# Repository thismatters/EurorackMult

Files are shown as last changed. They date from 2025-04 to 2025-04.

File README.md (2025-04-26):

# Signal Multiplier

The signal mulitplier, as the name implies, multiplies signals. This module is an active mult, meaning that the input signal is buffered and the output duplicate signals are also individually buffered to ensure the signal is faithfully duplicated.

This is an original design featuring a three-layer stackup with a front face, a layer for all the jacks, and a power/processing layer where all the SMD components are layed out.

As with other modules in this line, this mult features:
* Polarity protection so that a backward power header doesn't fry anything (twin series schotty diodes: BAT54SL),
* Full surface mount design.

The KiCAD project here uses the library/footprints [found in my companion repo](https://github.com/thismatters/EurorackKiCAD).

## Width

12hp on an [Intellijel 1U rack](https://intellijel.com/support/1u-technical-specifications/).

## Inputs

There are two signal jacks, the lower one normals to the upper.

## Outputs

There are six output jacks with the top set being fed by the top input, and the bottom set being fed by the bottom input. If there is no jack plugged into the bottom input socket then the bottom outputs will output the upper input's signal.

## Adjustment

No adjustment required.

## Vendors

There are part numbers in the [BOM](mult.csv) for many of the parts (not for basic passives though) at the following vendors:

* [Mouser](https://www.mouser.com): Needs no introduction. Get your ICs from here (or [digikey](https://www.digikey.com)).
* [Tayda Electronics](https://www.taydaelectronics.com/): Good supplier for passive components; audio jacks, and potentiometers. Their audio jacks are slightly smaller than the thonkiconn from thonk.
* [Love My Switches](https://lovemyswitches.com/): Has [really good knobs](https://lovemyswitches.com/anodized-aluminum-knob-the-lo-fi-1-4-smooth-shaft-12-5mm-od/) to go on those potentiometers!
* [OSHPark](https://oshpark.com/): Fast and (relatively) cheap PCB manufacturer. The [V0 circuit](https://oshpark.com/shared_projects/0YTEwnCD) has some issues (outlined below), use at your own risk.

## Changelog

### V1
- Removed extra Op Amp and replaced a TL074 with TL072
- Removed several resistors
- Updated design language
- Added standoffs between component board and jack board (increased module width to accomodate)
- Fixed some other bugs

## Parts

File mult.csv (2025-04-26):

# | Reference | Qty | Value | Footprint | DNP | Vendor | PartNum
1 | C1, C2 | 2 | 22u 50V | Capacitor_THT:CP_Radial_D5.0mm_P2.50mm
2 | C3, C4 | 2 | 100n | Capacitor_SMD:C_0805_2012Metric
3 | D1, D2 | 2 | BAT54S | Package_TO_SOT_SMD:SOT-23 |  | Mouser | 863-BAT54SLT1G
4 | J1 | 1 | Conn_02x05_Odd_Even | Eurorack:PinHeader_2x05_P2.54mm_Vertical |  | Tayda | A-2939
5 | J2, J3, J4, J5, J6, J7, J8, J9 | 8 | AudioJack2_SwitchT | Eurorack:AudioJack2_Tayda_A-2566 |  | Tayda | A-2566
6 | J10, J11, J12 | 3 | Conn_01x03_Pin | Connector_PinHeader_2.54mm:PinHeader_1x03_P2.54mm_Vertical
7 | J13, J14, J15 | 3 | Conn_01x03_Socket | Connector_PinSocket_2.54mm:PinSocket_1x03_P2.54mm_Vertical
8 | M1, M2 | 2 | Standoff | Eurorack:Standoff_M2.5x0.45-11mm |  | Digikey | 732-10549-ND
9 | M3, M4, M5, M6 | 4 | Screw | Eurorack:Screw_M2.5x0.45-6mm |  | Digikey | 36-29301-ND
10 | R1, R2 | 2 | 10 | Resistor_SMD:R_0805_2012Metric
11 | R3, R4, R5, R6, R7, R8 | 6 | 1K | Resistor_SMD:R_0805_2012Metric
12 | U1 | 1 | TL074 | Package_SO:SOIC-14_3.9x8.7mm_P1.27mm |  | Mouser | 595-TL074CDR
13 | U2 | 1 | TL072 | Package_SO:SOIC-8_3.9x4.9mm_P1.27mm |  | Mouser | 595-TL072CDR

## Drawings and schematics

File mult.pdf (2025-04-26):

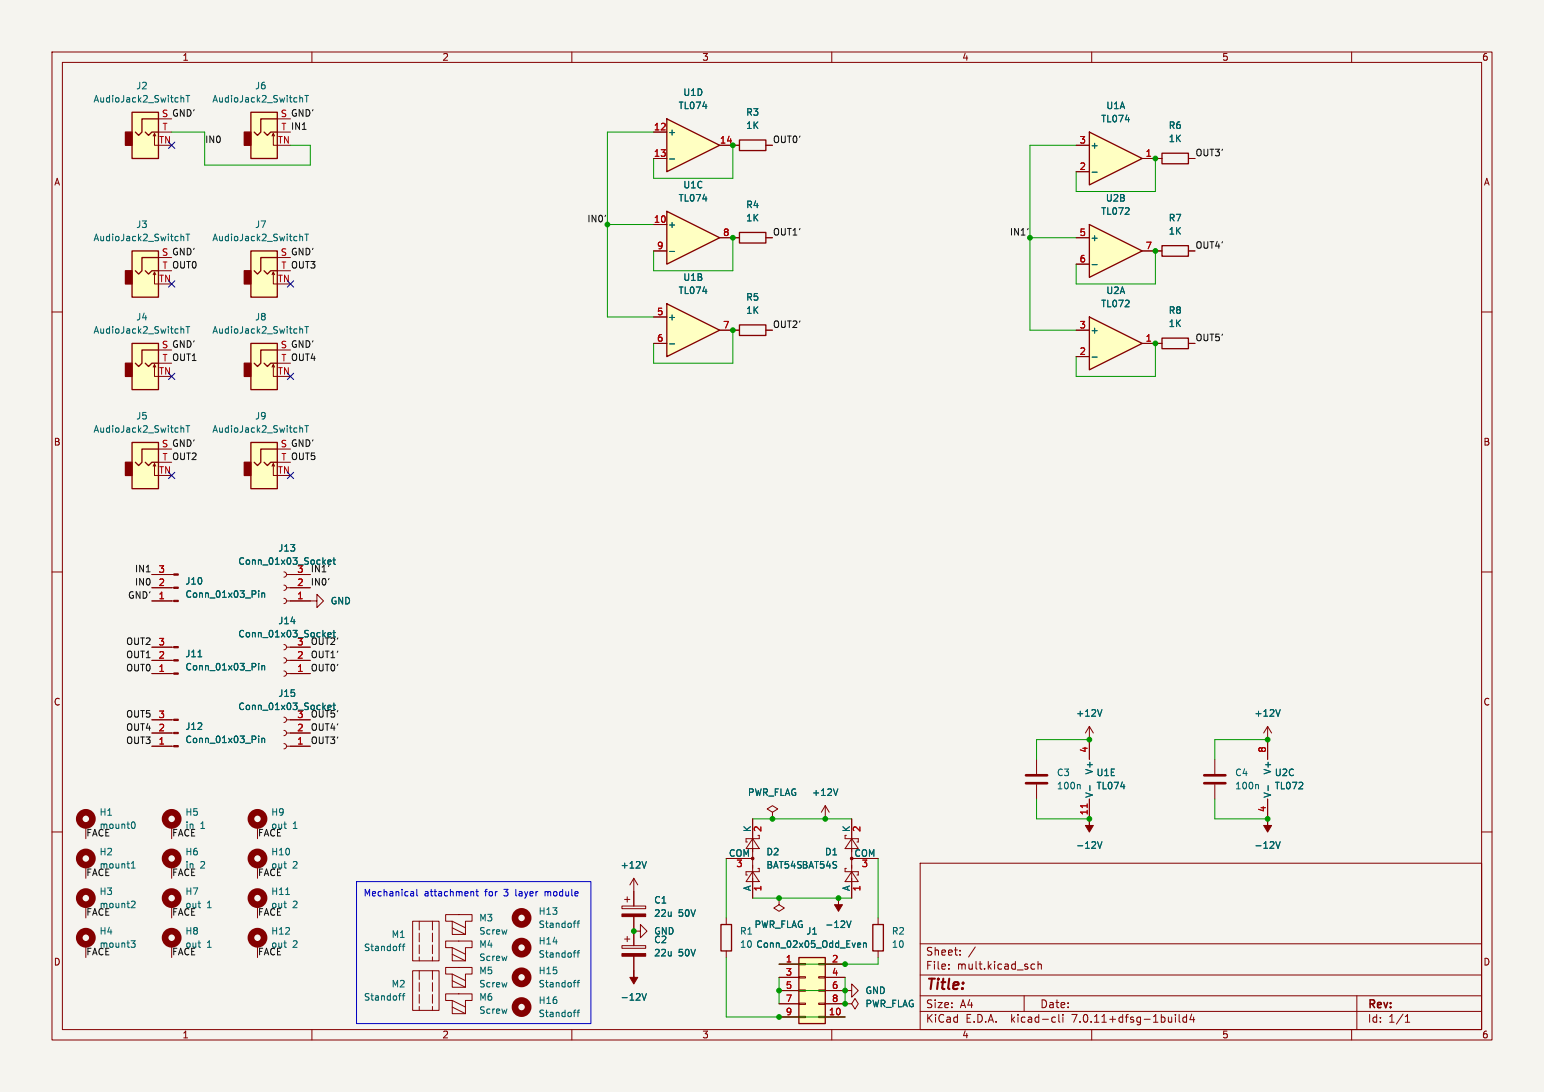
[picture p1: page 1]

Id: 1/1 Title: File: mult.kicad_sch Sheet: / R1

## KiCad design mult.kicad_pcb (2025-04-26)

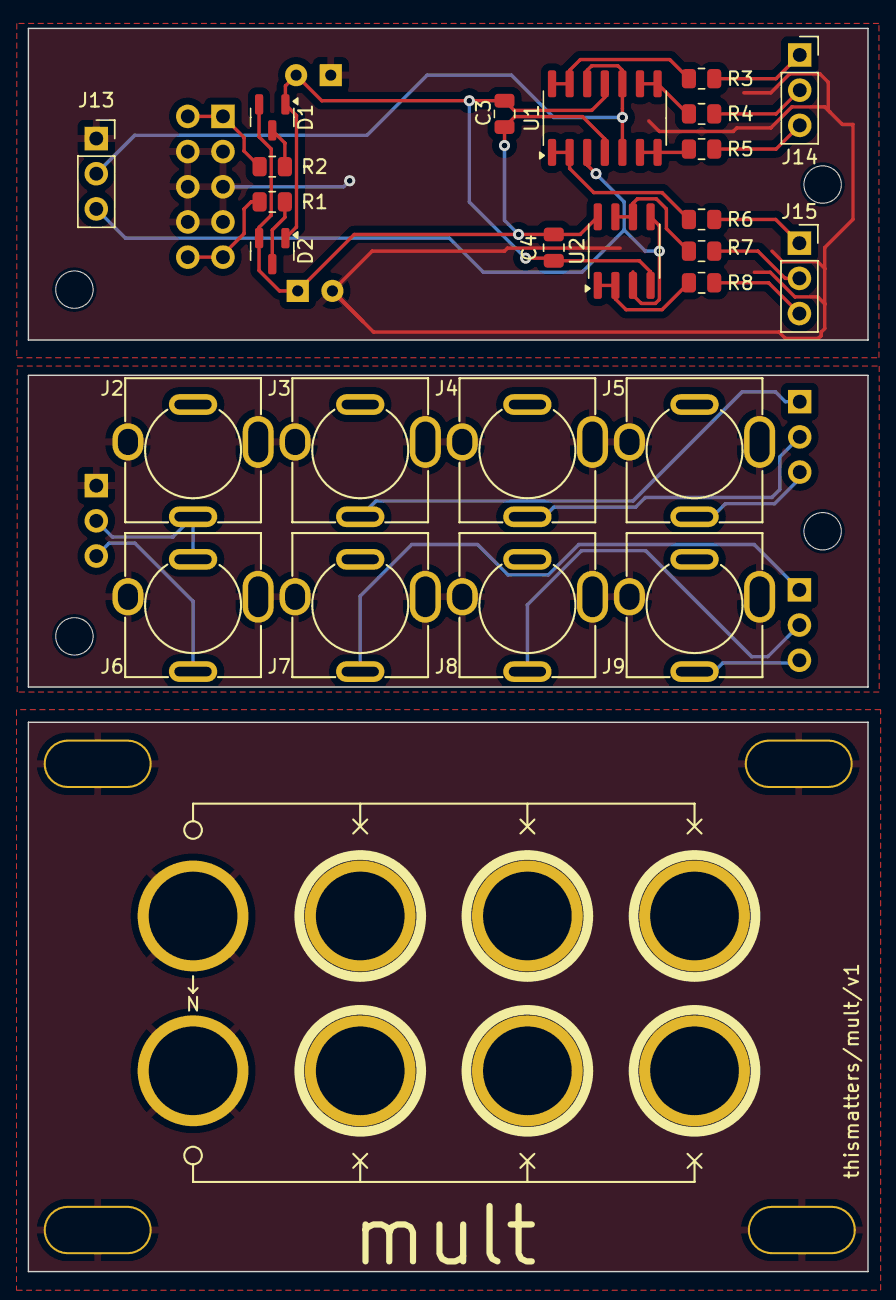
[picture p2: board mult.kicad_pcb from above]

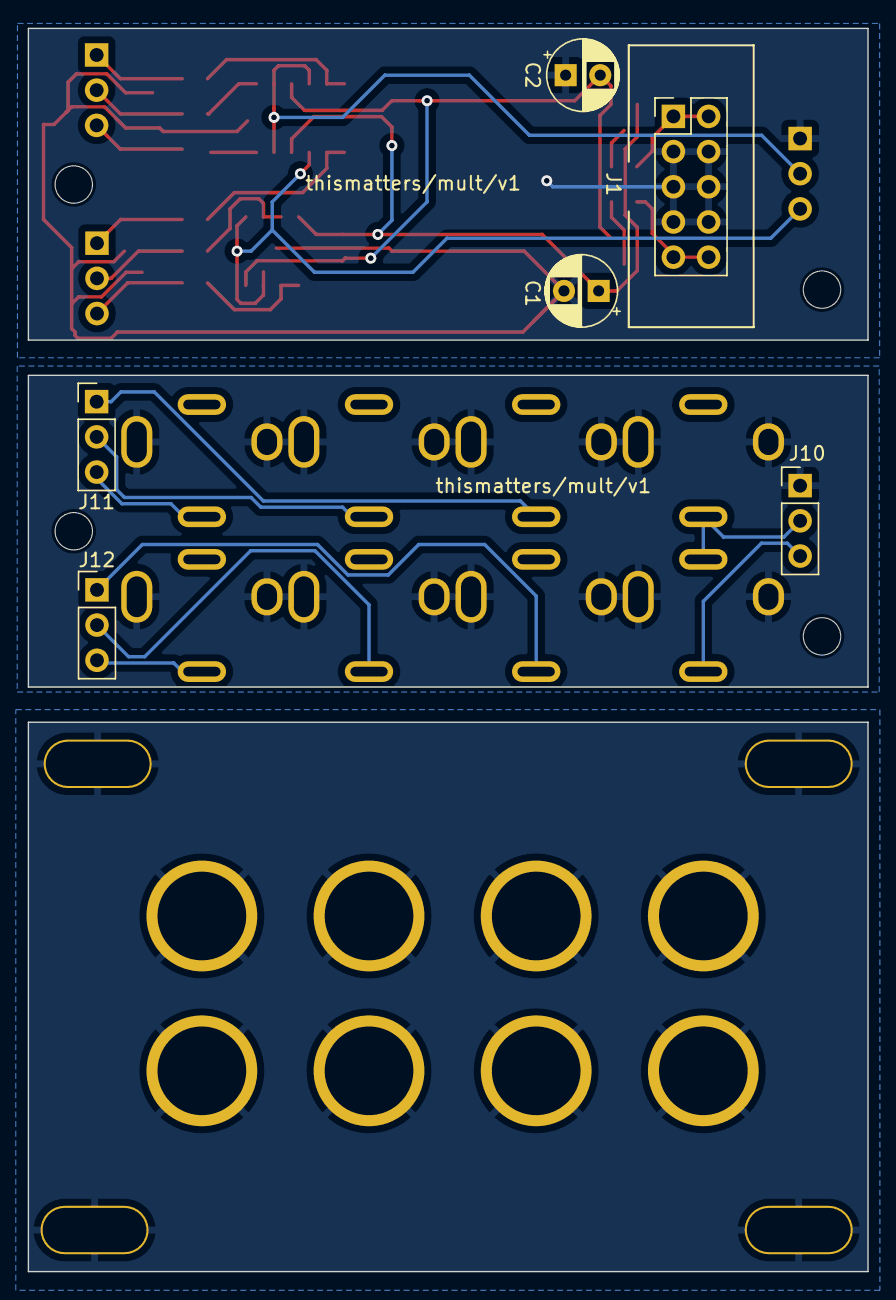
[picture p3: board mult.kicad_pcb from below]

Board: 2 copper layers, 60.6 x 89.7 mm, 47 parts (7 on the bottom side), 31 nets.

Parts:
C1, C2: 22u 50V; CP_Radial_D5.0mm_P2.50mm
C3, C4: 100n; C_0805_2012Metric
D1, D2: BAT54S; SOT-23
H1: mount0; Mech-MountingHole
H2: mount1; Mech-MountingHole
H3: mount2; Mech-MountingHole
H4: mount3; Mech-MountingHole
H5: in 1; Mech-AudioJack-Hole
H6: in 2; Mech-AudioJack-Hole
H7, H8, H9: out 1; Mech-AudioJack-Hole-Output
H10, H11, H12: out 2; Mech-AudioJack-Hole-Output
H13, H14, H15, H16: Standoff; MountingHole_2.7mm_M2.5
J1: Conn_02x05_Odd_Even; PinHeader_2x05_P2.54mm_Vertical
J2, J3, J4, J5, J6, J7, J8, J9: AudioJack2_SwitchT; AudioJack2_Tayda_A-2566
J10, J11, J12: Conn_01x03_Pin; PinHeader_1x03_P2.54mm_Vertical
J13, J14, J15: Conn_01x03_Socket; PinSocket_1x03_P2.54mm_Vertical
R1, R2: 10; R_0805_2012Metric
R3, R4, R5, R6, R7, R8: 1K; R_0805_2012Metric
U1: TL074; SOIC-14_3.9x8.7mm_P1.27mm
U2: TL072; SOIC-8_3.9x4.9mm_P1.27mm

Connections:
+12V: C1.1, C3.1, C4.1, D1.2 (K), D2.2 (K), U1.4 (V+), U2.8 (V+)
-12V: C2.2, C3.2, C4.2, D1.1 (A), D2.1 (A), U1.11 (V-), U2.4 (V-)
/FACE: H1.1, H2.1, H3.1, H4.1, H5.1, H6.1, H7.1, H8.1, H9.1, H10.1, H11.1, H12.1
/GND': J2.S, J3.S, J4.S, J5.S, J6.S, J7.S, J8.S, J9.S, J10.1
/IN0: J2.T, J6.TN, J10.2
/IN0': J13.2, U1.5 (+), U1.10 (+), U1.12 (+)
/IN1: J6.T, J10.3
/IN1': J13.3, U1.3 (+), U2.3 (+), U2.5 (+)
/OUT0: J3.T, J11.1
/OUT0': J14.1, R3.2
/OUT1: J4.T, J11.2
/OUT1': J14.2, R4.2
/OUT2: J5.T, J11.3
/OUT2': J14.3, R5.2
/OUT3: J7.T, J12.1
/OUT3': J15.1, R6.2
/OUT4: J8.T, J12.2
/OUT4': J15.2, R7.2
/OUT5: J9.T, J12.3
/OUT5': J15.3, R8.2
GND: C1.2, C2.1, J1.3, J1.4, J1.5, J1.6, J1.7, J1.8, J13.1
unnamed: D1.3 (COM), R2.1
unnamed: D2.3 (COM), R1.1
unnamed: J1.1, J1.2, R2.2
unnamed: J1.9, J1.10, R1.2
unnamed: R6.1, U1.1, U1.2 (-)
unnamed: R5.1, U1.6 (-), U1.7
unnamed: R4.1, U1.8, U1.9 (-)
unnamed: R3.1, U1.13 (-), U1.14
unnamed: R8.1, U2.1, U2.2 (-)
unnamed: R7.1, U2.6 (-), U2.7

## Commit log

2024-07-20 forgot to hit save
    [mult.kicad_sch]
2024-08-13 Bugfixes from v0
    [mult.kicad_pcb, mult.kicad_sch]
2025-04-26 prepping v1
    [mult.csv, mult.kicad_pcb, mult.kicad_sch]
